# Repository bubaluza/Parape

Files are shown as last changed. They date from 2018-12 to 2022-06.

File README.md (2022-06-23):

# Parape
PARAPE is a device developed for Project Class at UEPG (Universidade Estadual de Ponta Grossa - State University of Ponta Grossa).
The class proposes the students to develop and solve a real client problem using commercial and industrial standards from the documentation to the implementation.
PARAPE covers physiotherapeutic monitoring of the action of walk, alarming the user by pulsing a motor when they did the movement incorrectly while the device is attached to their legs;

The client in use was a kid with celebral palsy that walked wrong when not giving attention. The objective was to alert the user so they could remember to walk in the right way.

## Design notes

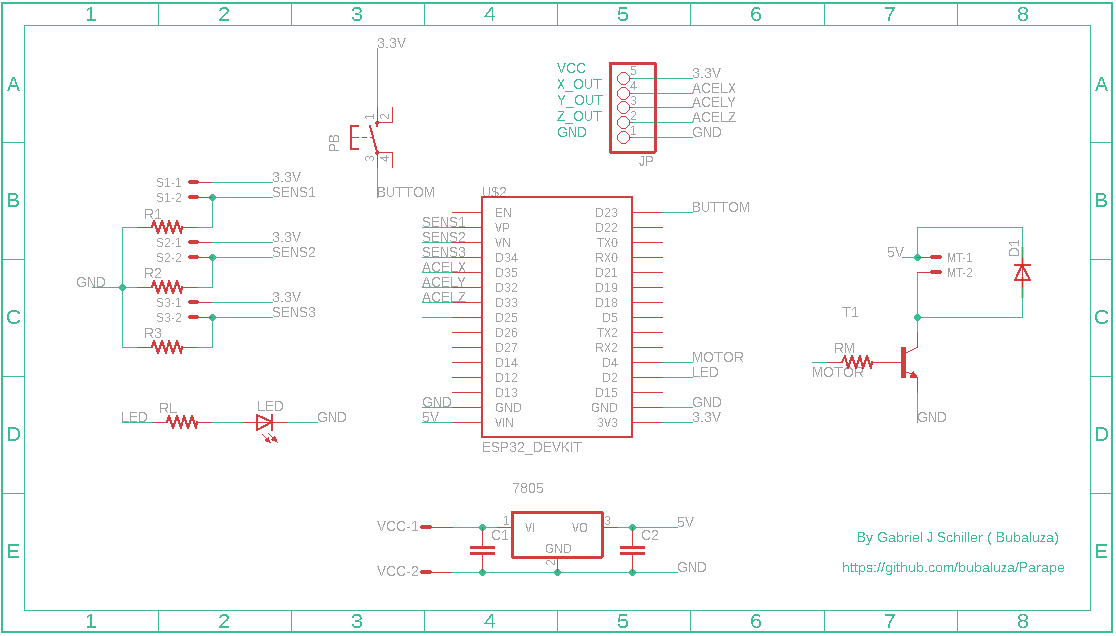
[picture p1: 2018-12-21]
Files/schematic.png

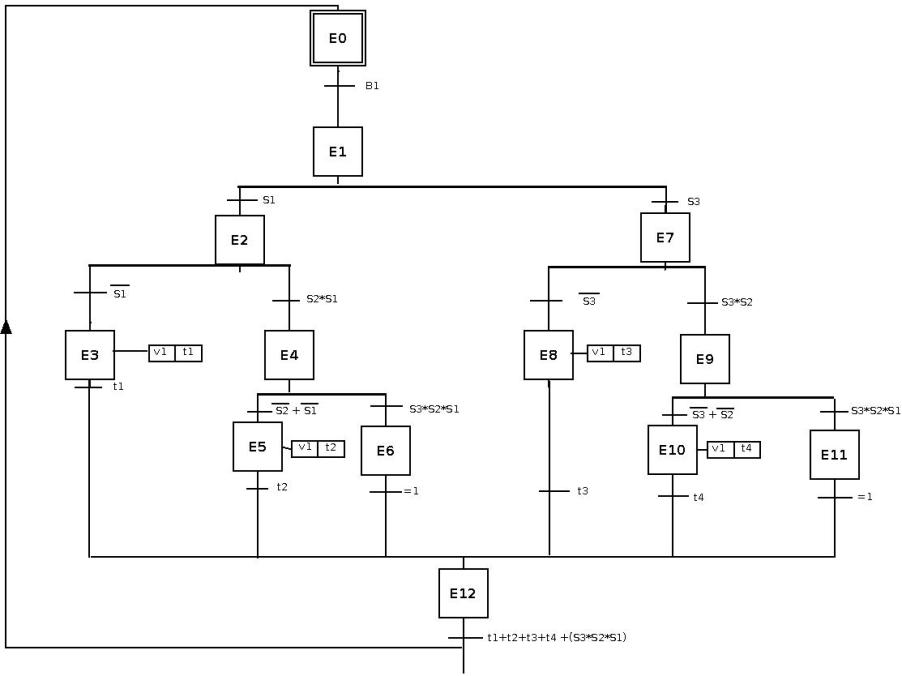
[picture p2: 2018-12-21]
Files/grafcet.jpeg

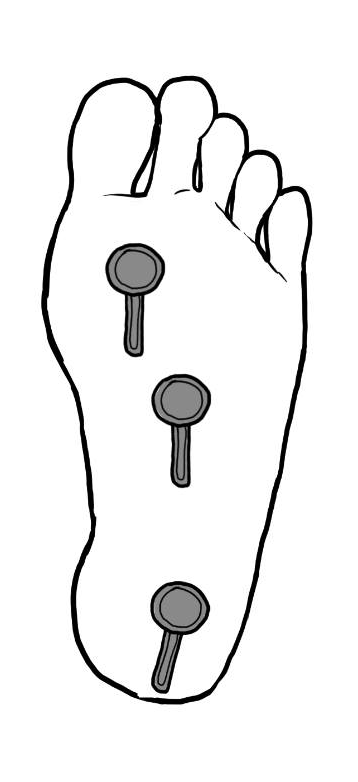
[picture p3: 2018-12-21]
Files/SensorPlace.png

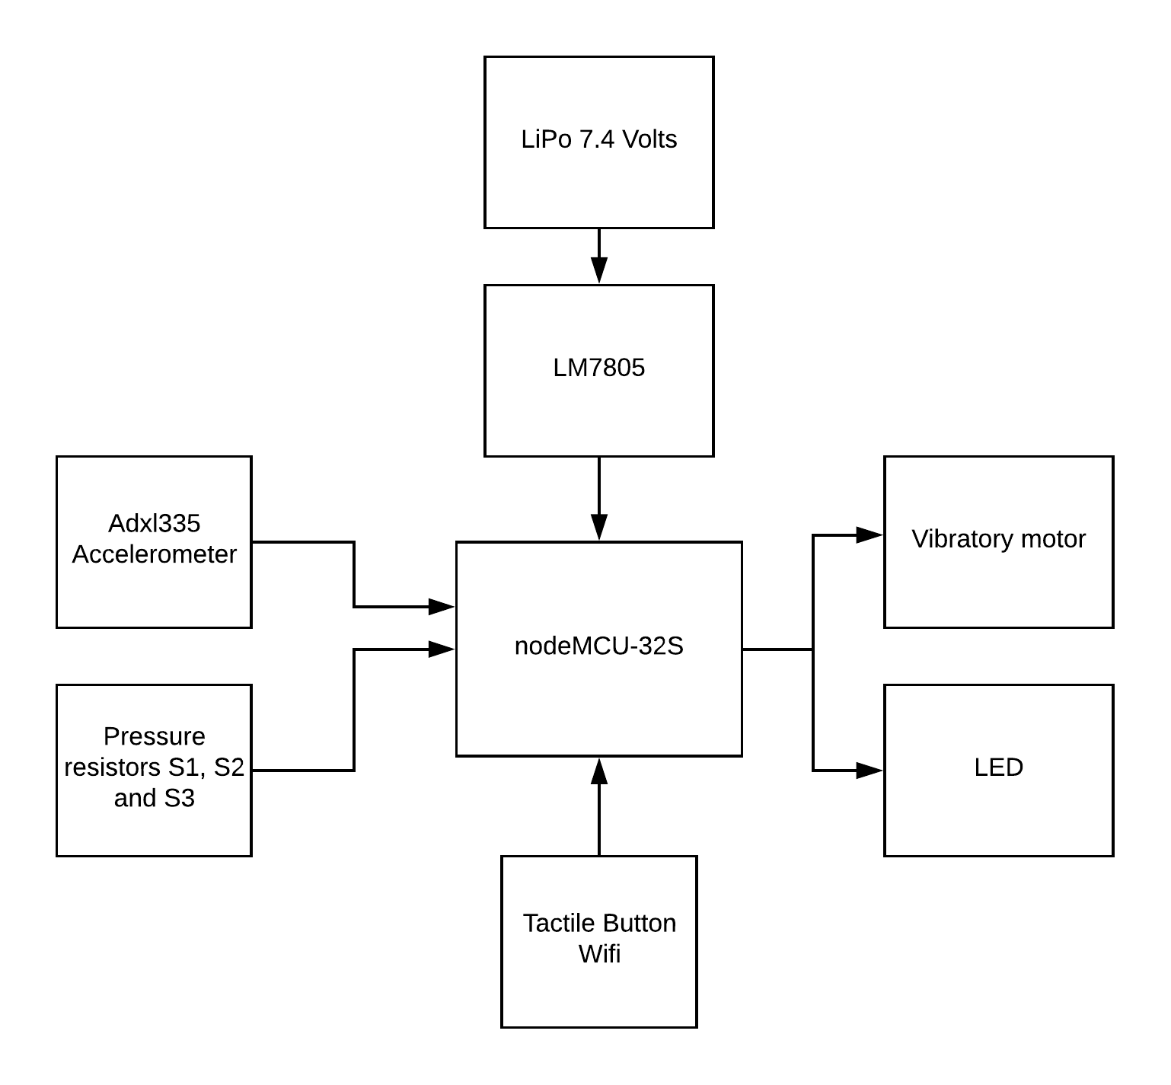
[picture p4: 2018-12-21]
Files/block diagram.png

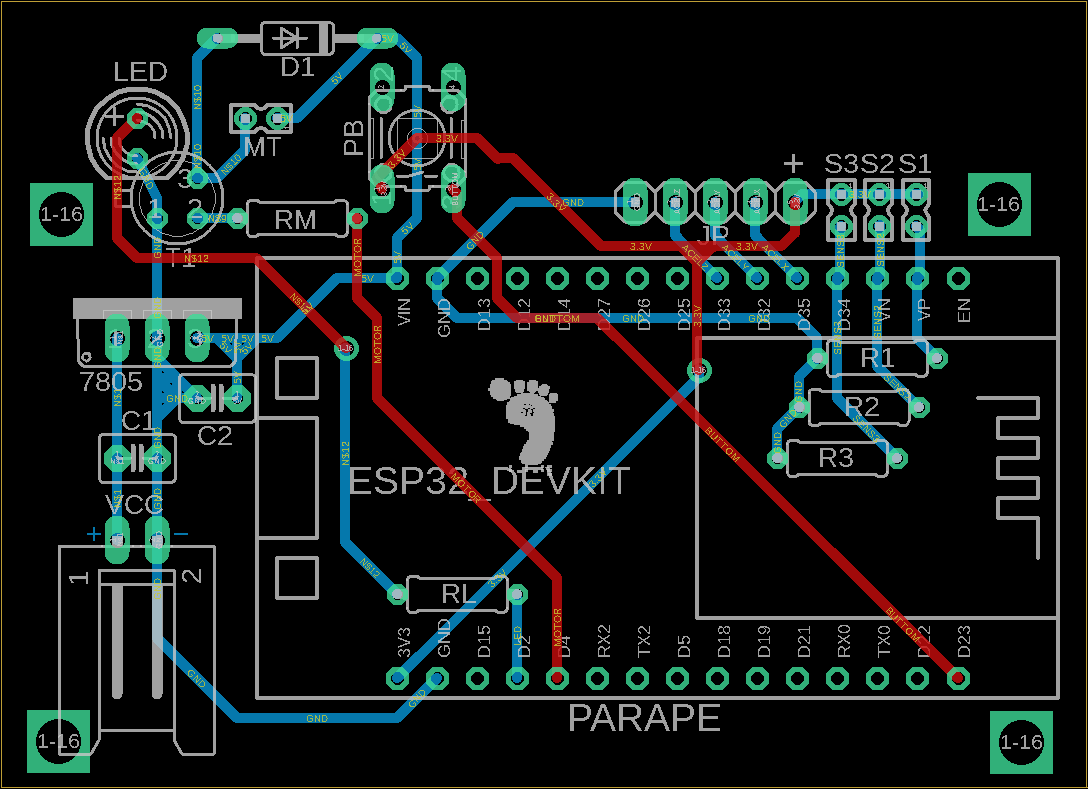
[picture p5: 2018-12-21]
Files/board.png

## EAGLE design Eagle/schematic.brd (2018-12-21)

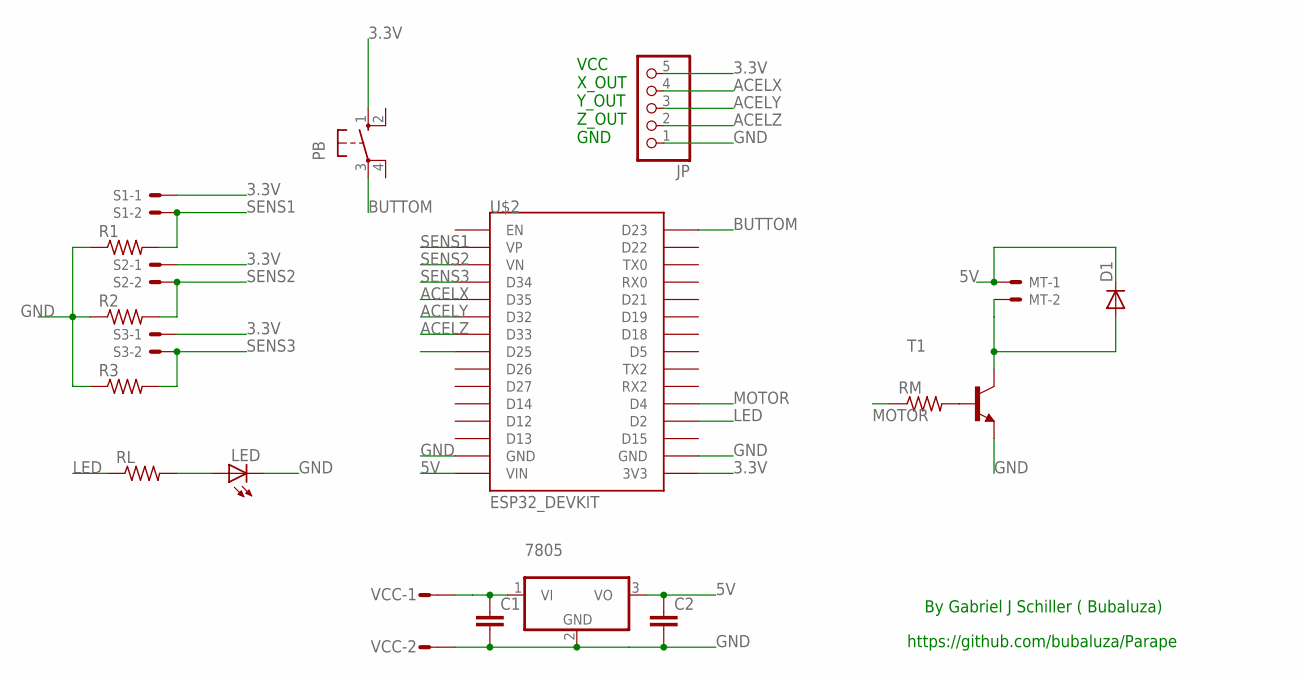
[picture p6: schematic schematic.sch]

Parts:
7805: 786TV; TO220V
C1, C2: C2,5-3; C2.5-3
D1: 1N4148DO35-10; DO35-10
JP: PINHD-1X5; 1X05
LED: LED5MM
MT: 332-02
PB: 10-XX; B3F-10XX
R1, R2, R3: R-US_0207/7; 0207/7
RL: R-US_0207/7; 0207/7
RM: R-US_0207/7; 0207/7
S1, S2, S3: 332-02
T1: 2N2222; TO18
U$2: ESP32_DEVKIT
VCC: L02P

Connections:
3.3V: JP.5, PB.1 (S), S1.1, S2.1, S3.1, U$2.3V3
5V: 7805.3 (VO), C2.1, D1.C, MT.1, U$2.VIN
ACELX: JP.4, U$2.D35
ACELY: JP.3, U$2.D32
ACELZ: JP.2, U$2.D33
BUTTOM: PB.3, U$2.D23
GND: 7805.2 (GND), C1.2, C2.2, JP.1, LED.K (C), R1.1, R2.1, R3.1, T1.1 (E), U$2.GND@1 (GND), U$2.GND@2 (GND), VCC.2
LED: RL.1, U$2.D2
MOTOR: RM.1, U$2.D4
unnamed: 7805.1 (VI), C1.1, VCC.1
unnamed: RM.2, T1.2 (B)
unnamed: D1.A, MT.2, T1.3 (C)
unnamed: LED.A, RL.2
SENS1: R1.2, S1.2, U$2.VP
SENS2: R2.2, S2.2, U$2.VN
SENS3: R3.2, S3.2, U$2.D34

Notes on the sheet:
VCC X_OUT Y_OUT Z_OUT GND
By Gabriel J Schiller ( Bubaluza)
https://github.com/bubaluza/Parape

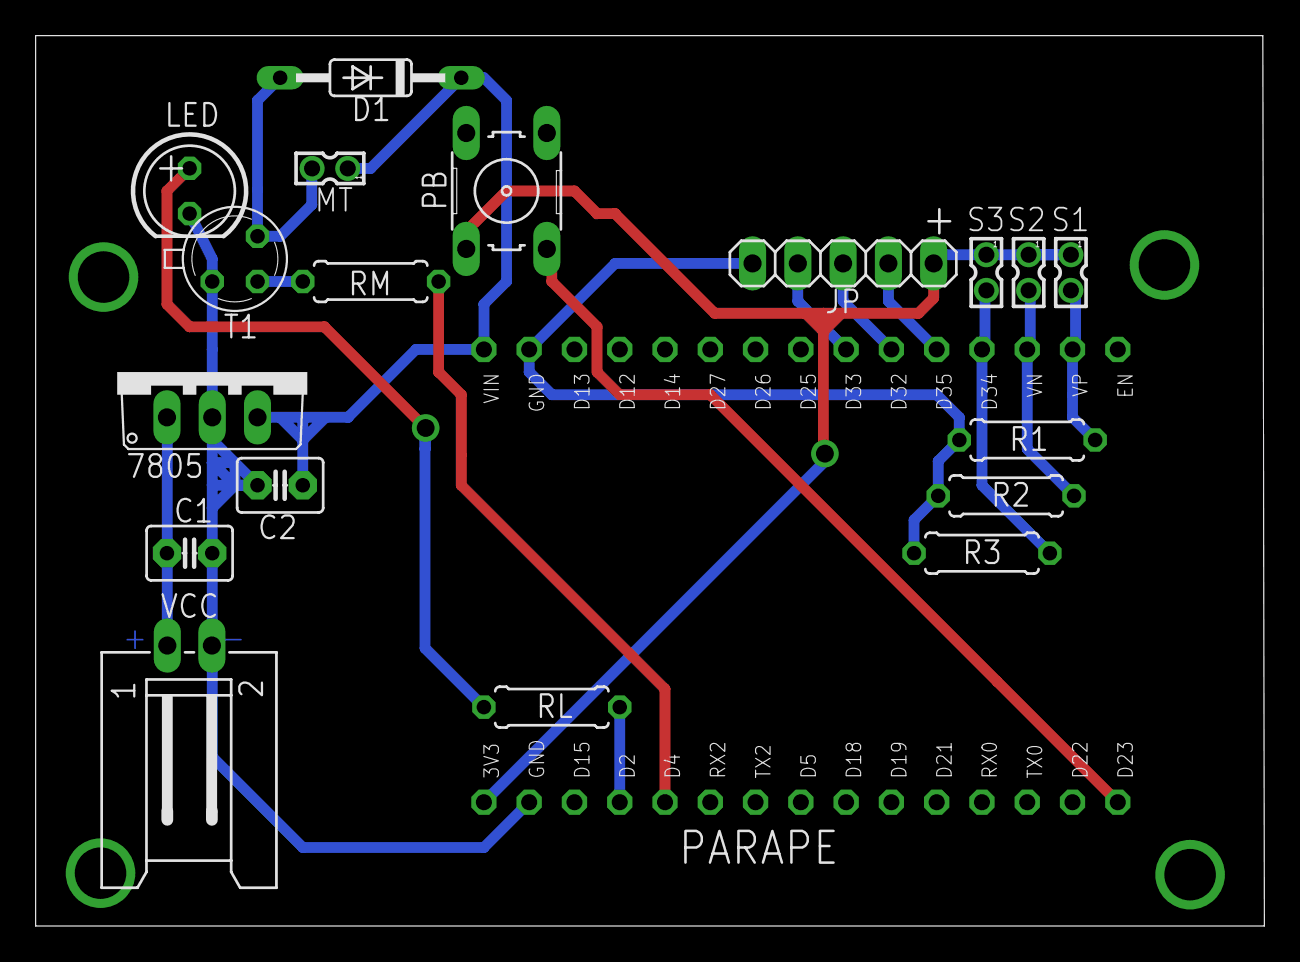
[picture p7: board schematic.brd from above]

Board: 2 copper layers, 68.9 x 49.9 mm, 19 parts (0 on the bottom side), 16 nets.

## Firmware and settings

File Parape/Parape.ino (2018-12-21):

/*                      --------------- SOFTWARE PARAPE ---------------
    AUTHOR: GABRIEL J SCHILLER
            ANSELMO NETO
    Software destined to the PARAPE projec. The project cover the analyse, processing and the action to
    the perfect step-walk. The main reason of this project was to be used on a kid that itself walking
    was weakened, showing to him when he walk wrong.
    Software destined to load on a ESP-32.
    Source code and more information: https://github.com/bubaluza/Parape */

// --------------- LIBRARIES INCLUDED ---------------
#include "WiFi.h"                                                   // High level library to ESP-32 WIFI
#include "esp_wifi.h"                                              // Low level library to ESP-32 WIFI
#include "FS.h"                                                     // File System
#include "SPIFFS.h"                                                 // SPIFFS
// --------------- OBJECT INSTANCE ---------------
WiFiServer server (80);                                             //Instance a WifiServer object 'server' on port 80
// --------------- TIMER POINTERS ---------------
hw_timer_t * timer = NULL;                                          // Timer pointer 1
hw_timer_t * timer2 = NULL;                                         // Timer pointer 2
// --------------- SSID/PASSWORD ESP32 ---------------
const char *ssid = "PARAPE";                                        // Name SSID
const char *password = "parape123";                                 // password to WiFi
// --------------- SPIFFS ---------------
#define FORMAT_SPIFFS_IF_FAILED true
// --------------- INPUT PIN ---------------
#define PinValueSensorHeel 34                                       //Read Pin of Heel Sensor
#define PinValueSensorCenter 39                                     //Read Pin of Center Sensor
#define PinValueSensorTip 36                                        //Read Pin of Tip Sensor
#define PinAccelX  35                                               //Read Pin of accelerometer X
#define PinAccelY  32                                               //Read Pin of accelerometer Y
#define PinAccelZ  33                                              //Read Pin of accelerometer Z
#define PinButton 23
// --------------- OUTPUT PIN ---------------
#define PinMotor 4                                                  //Motor Pin
#define PinLED 2                                                    // LED Pin
// --------------- STRENGTH LIMIT SENSOR ---------------
#define StrLimit 1500                                               //Ac-Dc Limit
// --------------- CONFIG DEFAULT ---------------
#define defaultPwm 50                                               //Default configuration of Motor PWM intensity
#define defaultJoke 2                                               //Default configuration of Playtime
// --------------- TIME DEFINE ---------------
#define TimeMotorMs 3000                                            //Vibration Time
#define TimeLockedUs 60000000                                       //Locked Up time Playtime
#define TimeCheckUs 30000000                                        //Check Time Playtime
// ---------------- VAR CONFIG LOADED -------------------
short int pwmLoad;                                                  //Use/Load PWM Intensity
short int activeJokeLoad;                                           //Use/Load Playtime
int wrongStepsLoad;                                                 //Use/load wrong Steps
// ---------------- SENSOR VAR VALUE ----------------
int ValueSensorHeel = 0;                                            //Heel Sensor Value
int ValueSensorCenter = 0;                                          //Center Sensor Value
int ValueSensorTip = 0;                                             //Tip Sensor  Value
float ValueAccelX = 0.0;                                                //accelerometer X Value
float ValueAccelY = 0.0;                                                //accelerometer Y Value
float ValueAccelZ = 0.0;                                                //accelerometer Z Value
// ---------------- AUX VAR ----------------
bool exitL = 0;                                                      //flag to exit if steps-sequence are right
bool flag = 0;                                                      //flag to Activate Motor if steps-sequence are Wrong
bool lockedSystem = 0;                                              //flag to Locked up System
bool interruption = 0;                                              //flag to Interruption System
bool cleaning = 0;                                                  //flag to clean flags
bool readB = 0;                                                      //Buttom Digital Read
bool wifiStatus = 0;                                                //Configuration Mode Status
int ActivadeMotorCheck = 0;                                         //Lower Limit Playtime
byte i=0;
int mean=20;

// ---------------- FUNCTIONS DECLARATION ----------------
void getSinal() ;                                                   //Read Sensors
void pulseMotor();                                                  //Vibrate Motor
void checkMotor() ;                                                 //Check activate number Motor
void startTimer();                                                  //Start Timer 1
void stopTimer();                                                   //Stop Timer 1
void interrupionBlink();                                            //Playtime LED blink
void startTimer2();                                                 //Start Timer 2
void stopTimer2();                                                  //Stop Timer 2
void htmlx();                                                       //configuration page
void appendFile(fs::FS &fs, const char * path, String  message);    //Change File content
void deleteFile(fs::FS &fs, const char * path);                     //Delete File
void listDir(fs::FS &fs, const char * dirname, uint8_t levels);     //List Director (only to check)
void readFile(fs::FS &fs, const char * path);                       //Read File content to Serial(only to check)
String readFileTo(fs::FS &fs, const char * path);                   //Read File content
bool isStopped();                                                   //Check if the person is standing
// ---------------- STARTUP SETUP ----------------
void setup() {
  delay(2000);
  pinMode(PinLED, OUTPUT);
  digitalWrite (PinLED, HIGH);
  Serial.begin(115200);
  if (!SPIFFS.begin(FORMAT_SPIFFS_IF_FAILED)) {                     //Mount SPIFFS
    Serial.println("SPIFFS Mount Failed");
    return;
  }
  if (readFileTo(SPIFFS, "/pwm.txt") == "error") {                  //Check if dont exist file/Content or Open Error
    deleteFile(SPIFFS, "/pwm.txt");
    appendFile(SPIFFS, "/pwm.txt", (String)defaultPwm);             //Put Default PWM file
  }
  pwmLoad = (readFileTo(SPIFFS, "/pwm.txt")).toInt();               //Read PWM file

  if (readFileTo(SPIFFS, "/playtime.txt") == "error") {             //Check if dont exist file/Content or Open Error
    deleteFile(SPIFFS, "/playtime.txt");
    appendFile(SPIFFS, "/playtime.txt", (String)defaultJoke);       //Put Default Playtime file
  }
  activeJokeLoad = (readFileTo(SPIFFS, "/playtime.txt")).toInt();   //Read PWM file

  if (readFileTo(SPIFFS, "/steps.txt") == "error") {                //Check if dont exist file/Content or Open Error
    deleteFile(SPIFFS, "/steps.txt");
    appendFile(SPIFFS, "/steps.txt", "0");                          //Put '0' on Step File
  }
  wrongStepsLoad = (readFileTo(SPIFFS, "/steps.txt")).toInt();      //Read Steps File
  ledcAttachPin(PinMotor, 2);                                       //put PinMotor on PWM channel 2
  ledcSetup(2, 500, 10);                                            //set PWM channel 2: 500 hz, 10 bits resolution

  WiFi.softAP(ssid, password);                                      //Start Wifi on AP Mode
  esp_wifi_stop();                                                  //Stop WiFi
  delay(5000);
  Serial.println("ESP32 started and openned Serial");
  pinMode(PinMotor, OUTPUT);
  pinMode(PinButton, INPUT_PULLDOWN);
  digitalWrite (PinMotor, LOW); 
  server.begin();                                                   //Start a WiFi server
  startTimer();
  digitalWrite (PinLED, LOW);
}


//---------------- MAIN LOOP ----------------
void loop() {
  if (lockedSystem) {
    Serial.print("locked system for");
    Serial.print(TimeLockedUs / 1000000);
    Serial.println("seconds.");

    startTimer2();
    delayMicroseconds(TimeLockedUs);
    lockedSystem = 0;
    startTimer();
    ActivadeMotorCheck = 0;
  }

  if (cleaning) {
    ActivadeMotorCheck = 0;
    cleaning = 0;
  }

  readB = digitalRead(PinButton);
  if (readB == 1) {
    while (readB == 1)                                               //wait Release buttom
      readB = digitalRead(PinButton);
    if (wifiStatus == 0) {                                          //if wifi are OFF
      esp_wifi_start();                                             //Start Wifi
      digitalWrite(PinLED, wifiStatus = 1);
    }
    else if (wifiStatus == 1) {                                     //if wifi are ON
      esp_wifi_stop();                                              //Stop Wifi
      digitalWrite(PinLED, wifiStatus = 0);
    }
    delay(6000);
  }
  if (wifiStatus) {                                                 //configuration Mode listening
    htmlx();
  }
  else {                                                            //evaluate Heel -> Tip Sensor
    getSinal();                                                 
    if ( (!isStopped()) && (ValueSensorHeel > StrLimit ) ) {
      while (ValueSensorHeel > StrLimit || flag != 1) {
        getSinal();
        if (ValueSensorTip > StrLimit) {
          exitL = 1;
          while (ValueSensorTip > StrLimit)
            getSinal();                                      
          break;
        }
        if (exitL == 1)
          break;
        if (ValueSensorHeel <= StrLimit)
          flag = 1;
      }
    }
    else if ((!isStopped()) && ValueSensorTip > StrLimit) {         //Evaluate Tip -> Heel Sensor
      while (ValueSensorTip > StrLimit || flag != 1) {
        getSinal();
        if (ValueSensorHeel > StrLimit) {
          exitL = 1;
          while (ValueSensorHeel > StrLimit)
            getSinal();                                
          break;
        }
        if (exitL == 1)
          break;
        if (ValueSensorTip <= StrLimit)
          flag = 1;
      }
    }
    else if ((!isStopped()) && ValueSensorCenter > StrLimit ) {      //Evaluate Center -> Tip Sensor (Stair Walking)
      while (ValueSensorCenter > StrLimit || flag != 1) {
        getSinal();
        if (ValueSensorTip > StrLimit) {
          exitL = 1;
          while (ValueSensorTip > StrLimit)
            getSinal();                                 
          break;
        }    
        if (exitL == 1)
          break;
        if (ValueSensorCenter <= StrLimit)
          flag = 1;
      }
    }
    
    if (flag == 1) {                                                //if Walked wrong Pulse Motor
      ActivadeMotorCheck++;
      wrongStepsLoad++;
      deleteFile(SPIFFS, "/steps.txt");
      appendFile(SPIFFS, "/steps.txt", (String)wrongStepsLoad);
      pulseMotor();
      flag = 0;
    }
    exitL = 0;
  }
}

// --------------- FUNCTIONS ---------------
void getSinal() {
  ValueSensorHeel = analogRead(PinValueSensorHeel);
  ValueSensorCenter = analogRead(PinValueSensorCenter);
  ValueSensorTip = analogRead(PinValueSensorTip);
}

void pulseMotor() {
  ledcWrite(2, map(pwmLoad, 0, 100, 350 , 1022));
  delay(TimeMotorMs);
  ledcWrite(2, 0);
}

void checkMotor() {
  cleaning = 1;
  if ((ActivadeMotorCheck >= activeJokeLoad) && !wifiStatus) {
    lockedSystem = 1;
    stopTimer();
  }
}

void startTimer() {
  timer = timerBegin(3, 80, true);
  timerAttachInterrupt(timer, &checkMotor, true);
  timerAlarmWrite(timer, TimeCheckUs, true);
  timerAlarmEnable(timer);
}

void stopTimer() {
  timerEnd(timer);
  timer = NULL;
}

void interrupionBlink() {
  digitalWrite(PinLED, interruption = !interruption);
  if ( lockedSystem == 0) {
    digitalWrite(PinLED, interruption = 0);
    stopTimer2();
  }
}

void startTimer2() {
  timer2 = timerBegin(2, 80, true);
  timerAttachInterrupt(timer2, &interrupionBlink, true);
  timerAlarmWrite(timer2, 500000, true);
  timerAlarmEnable(timer2);
}

void stopTimer2() {
  timerEnd(timer2);
  timer2 = NULL;
}

bool isStopped() {
    i=0;
  ValueAccelX = 0.0;
  ValueAccelY = 0.0;
  ValueAccelZ = 0.0;
  for(i;i<mean;i++){
   ValueAccelX += ((analogRead(PinAccelX))*3.3)/4095; //read from PinAccelX
   ValueAccelY += ((analogRead(PinAccelY))*3.3)/4095; //read from PinAccelY
   ValueAccelZ += ((analogRead(PinAccelZ))*3.3)/4095; //read from PinAccelZ
   delay(1);
  }
  ValueAccelX = ValueAccelX/mean;
  ValueAccelY = ValueAccelY/mean;
  ValueAccelZ = ValueAccelZ/mean;
  
  float mod=sqrt(   0.22*(pow(ValueAccelX,2)) + 2*(pow(ValueAccelY,2)) + 0.1*(pow(ValueAccelZ,2)) );

    if(  mod>=2.2 && mod <= 2.4 )
        return true;
          else{

            return false; 
          }
            
          
}

void htmlx() {
  WiFiClient client = server.available();                           // Listen for incoming clients
  String payload;
  String vibration;
  String playtime;
  String sleep;
  String line = "";
  if (client) {                                                     // If a new client connects,
    Serial.println("New Client");
    String request = "";
    while (client.connected()) {                                    // loop while the client's connected
      if (client.available()) {                                     // if there's bytes to read from the client,
        char c = client.read();                                     // read a byte
        request += c;
        if (c == '\n') {
          if (line.length() == 0) {
            client.println("HTTP/1.1 200 OK");
            client.println("Content-type:text/html");
            client.println("Connection: close");
            client.println();

            if (request.indexOf("GET /clear") >= 0) {
              wrongStepsLoad = 0;
              deleteFile(SPIFFS, "/steps.txt");
              appendFile(SPIFFS, "/steps.txt", "0");

              client.println("{\"message\": \"Passos Zerados\"}");
              client.println();
              break;
            } else if (request.indexOf("GET /reset") >= 0) {
              pwmLoad = defaultPwm;
              activeJokeLoad = defaultJoke;
              deleteFile(SPIFFS, "/pwm.txt");
              appendFile(SPIFFS, "/pwm.txt", (String)pwmLoad);
              deleteFile(SPIFFS, "/playtime.txt");
              appendFile(SPIFFS, "/playtime.txt", (String)activeJokeLoad);

              client.println("{\"message\": \"Dados Redefinidos\", \"data\": {\"vibration\": 50, \"playtime\": 2}}");
              client.println();
              break;
            } else if (request.indexOf("GET /save") >= 0) {
              int index = 0;
              String line = request.substring(request.indexOf("GET /") + 5);
              String information = "";
              while (line[index] != '\n') {
                information += line[index];
                index++;
              }
              payload = information.substring(0, information.indexOf(" HTTP/1.1"));
              vibration = payload.substring(payload.indexOf("vibration=") + 10, payload.indexOf('&'));
              String  playtime1 =  payload.substring(payload.indexOf("playtime=") + 9);
              playtime = playtime1.substring(0, playtime1.indexOf('&'));
              pwmLoad = vibration.toInt();
              activeJokeLoad = playtime.toInt();

              if (pwmLoad > 100)
                pwmLoad = 100;
              else if (pwmLoad < 0)
                pwmLoad = 0;

              if (activeJokeLoad < 1)
                activeJokeLoad = 1;

              deleteFile(SPIFFS, "/pwm.txt");
              appendFile(SPIFFS, "/pwm.txt", (String)pwmLoad);
              deleteFile(SPIFFS, "/playtime.txt");
              appendFile(SPIFFS, "/playtime.txt", (String)activeJokeLoad);

              Serial.println(readFileTo(SPIFFS, "/pwm.txt"));
              Serial.println(readFileTo(SPIFFS, "/playtime.txt"));

              client.println("{\"message\": \"Dados Salvos\"}");
              client.println();
              break;
            }
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

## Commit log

2018-12-04 I2c acc
2018-12-21 doc improve
    [schematic.brd, schematic.sch]
